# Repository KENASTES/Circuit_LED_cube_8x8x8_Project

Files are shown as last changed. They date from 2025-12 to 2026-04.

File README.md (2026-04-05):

<h1 align="center">Circuit & Electronic 8x8x8 LED Cube Project</h1>

## Overview 
"Repo นี้เป็นโปรเจกวิชา Circuit & Electronic ของผมตอนเรียนอยู่ KMITL โดยโปรเจคนี้เป็นหัวข้อที่ Assign มาจากอาจารย์อีกที โจทย์คือทำ Led Cube ขนาดใดก็ได้โดยจะนำโปรเจคนี้ไปให้เด็กพิการได้ใช้เป็นสื่อในการเรียนรู้ ตัวของโปรเจคเริ่มจากการเลือกใช้ โปรแกรมออกแบบและตัวหน้าที่ต่างๆ เราจะออกแบบ Model ของกล่องที่ใช้เป็นฐานเก็บวงจรและเป็น Base ให้กับตัว Led Cube ด้วย Solid Work 2023 แล้วนำตัวโมเดล Cad ไปปริ้นด้วย 3D Printer อีกที ตัววงจรจะออกแบบด้วย EasyEDA โดยใช้บอร์ด Control เป็น Arduino UNO R4 WIFI แล้วสื่อสารกับตัว Shift Register แบบ Serial in Parallel Out (SIPO) ด้วย Protocol SPI แล้วใช้ Transistor BD241C เป็น Low Side Switch ในการเปิดปิดและรับโหลดของหลอดไฟทั้ง Layer เนื่องจากกระแสในวงจรนั้นสูงมาก จากหลอดไฟ 20mA ทั้งเลเยอร์หรือก็คือ 64 หลอด 64 X 0.02 mA = 1.28A ซึ้งเสเปกโดยทั้วไปอาจจะใช้ขับหลอดไฟภายในเลเยอร์ไม่ได้ในส่วนของโปรแกรมจะสั่ง Input จาก 4X4 KeyPad แล้วใช้เป็น Logic Decision ในการเล่น Animation โดยตัวโค้ดในการออกแบบ Animation จะใช้จินตนาการว่า Led Cube คือการ Integrate พื้นที่ในแคลคูลัสแบบ Discrete 8X8X8 หรือแยก Position เป็น จุดออกมาจากการอินทีเกรตแล้วเขียนกราฟที่มี Animation ลงไปในสมการให้ตัว โหนดแต่ละโหนดเล่นตามสมการจึงเป็นสาเหตุว่าใน Code เป็นสมการแทบจะทั้งหมด"

---

LED Cube Animation

## Tech Stack 
- $\color{cyan}{\textbf{Hardware :}}$ Arduino UNO R4 WIFI, 74HC595
- $\color{orange}{\textbf{Firmware :}}$ C++ (Arduino Framework)
- $\color{purple}{\textbf{Design :}}$ Solid Work 2023, EasyEDA

## Concept 
เราใช้การควบคุมแบบ $8 \times 8 \times 8$ โดยแบ่งเป็น:
- $\color{green}{\textbf{Columns : }}$ 64 จุด ควบคุมผ่าน 8x Shift Registers
- $\color{green}{\textbf{Layers : }}$ 8 ชั้น ควบคุมผ่าน Transistor Darlington Array

## Build Process 
| Building the Jig | Soldering Layers | Final Assembly |
| :---: | :---: | :---: |
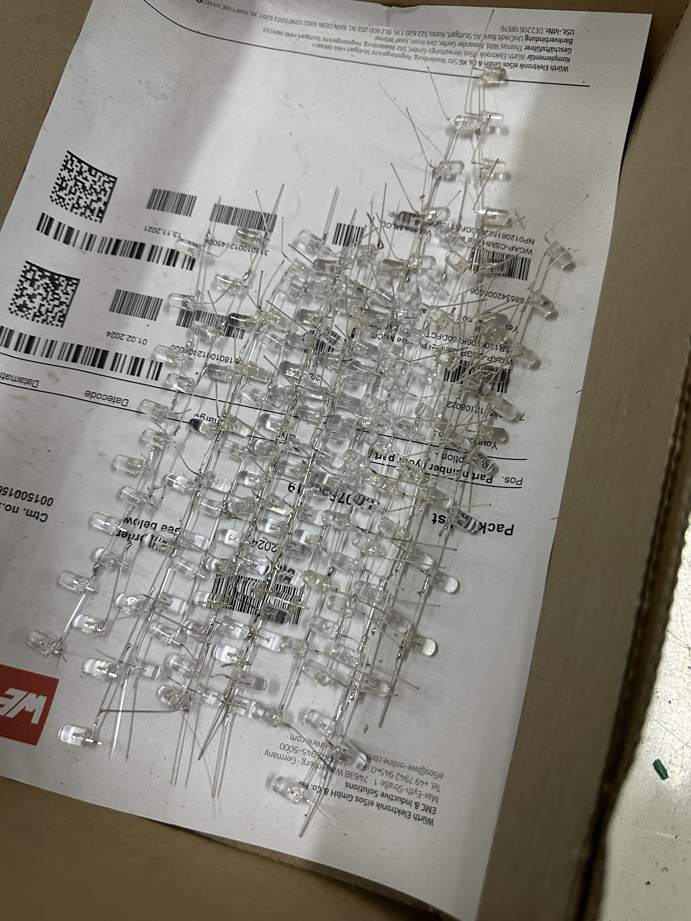
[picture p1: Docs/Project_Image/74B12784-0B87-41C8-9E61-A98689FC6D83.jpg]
Building the Jig
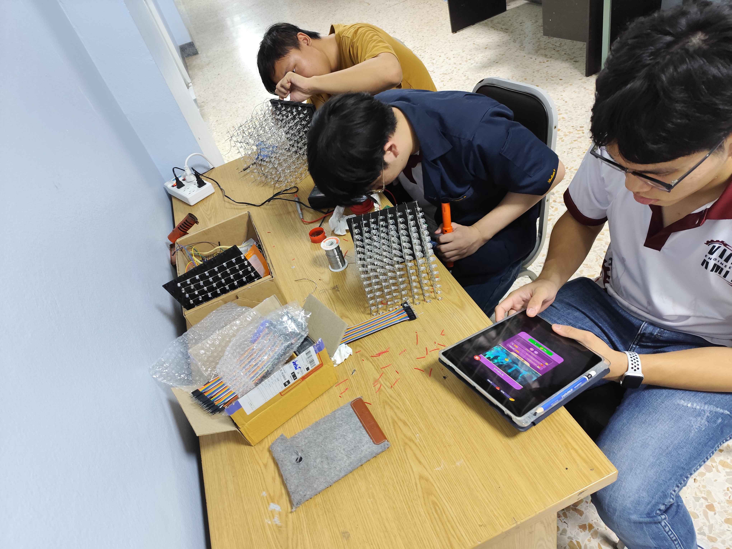
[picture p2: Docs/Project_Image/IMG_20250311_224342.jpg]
Soldering Layers
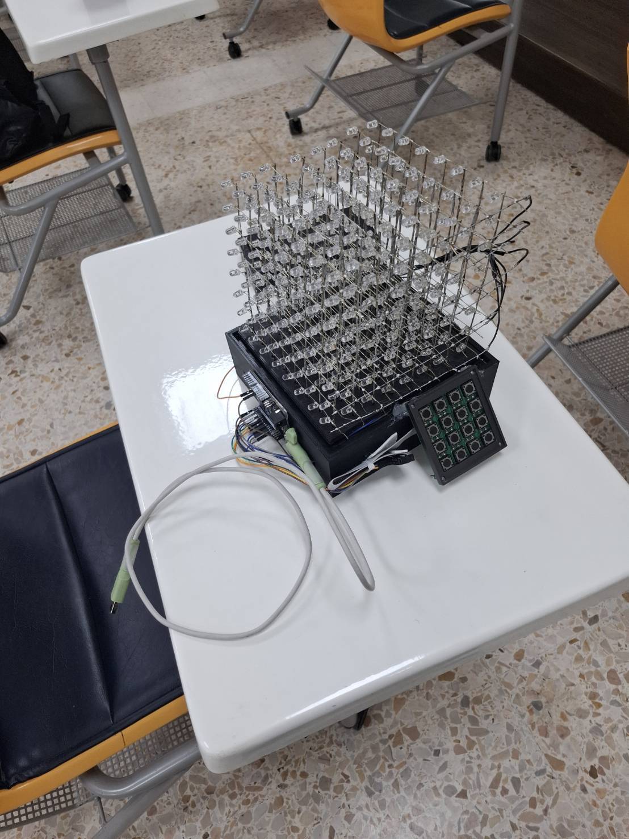
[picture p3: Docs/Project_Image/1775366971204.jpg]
Final Assembly
|  |  |  |

## Contributors 
- $\color{red}{\textbf{Panya Triprom}}$ ([@KENASTES](https://github.com/KENASTES))
- $\color{red}{\textbf{Rathiphat Buakaew}}$ ([@ratiphat2548](https://github.com/ratiphat2548))
- $\color{red}{\textbf{Ploynumthong Chaiyotha}}$ ([@Ploynumthong](https://github.com/Ploynumthong))

---
*Created for Educational Purpose @KMITL*

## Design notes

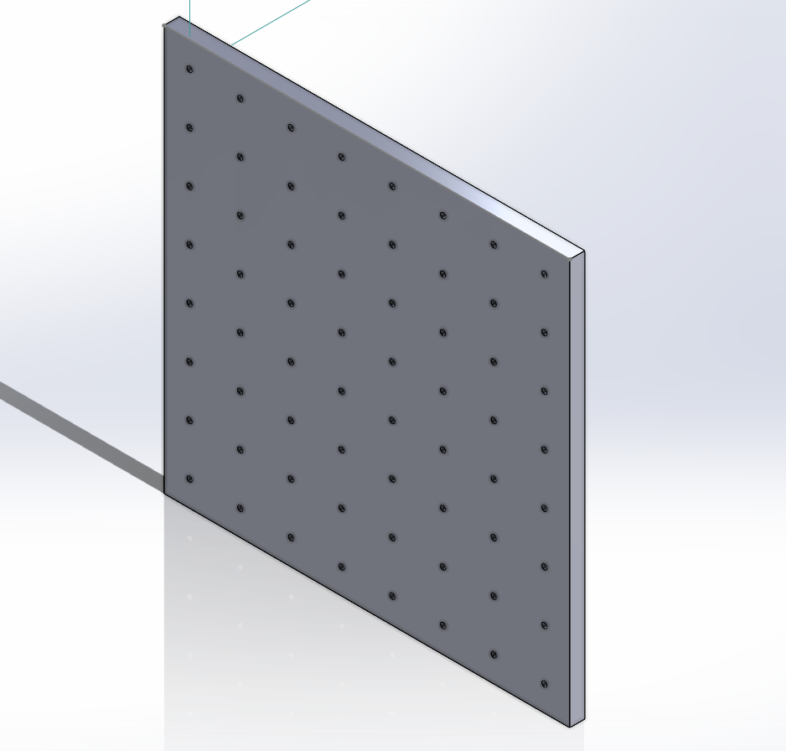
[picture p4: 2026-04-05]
Hardware/Led_Cube_Box_Model/Led Metrix Stand Model View.png

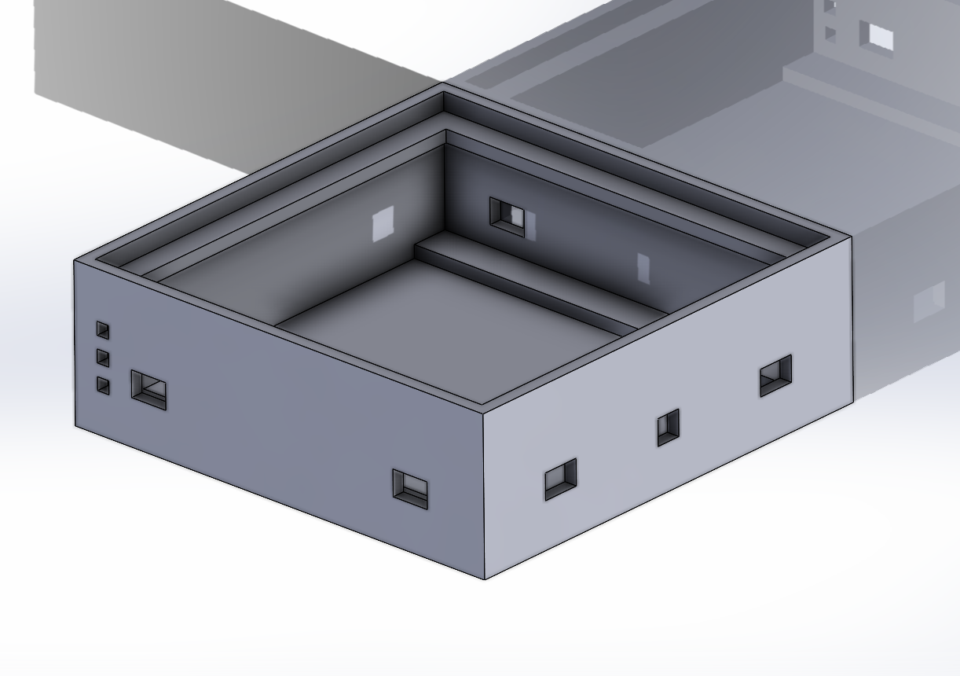
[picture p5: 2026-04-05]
Hardware/Led_Cube_Box_Model/Led Metrix Box Model View.png

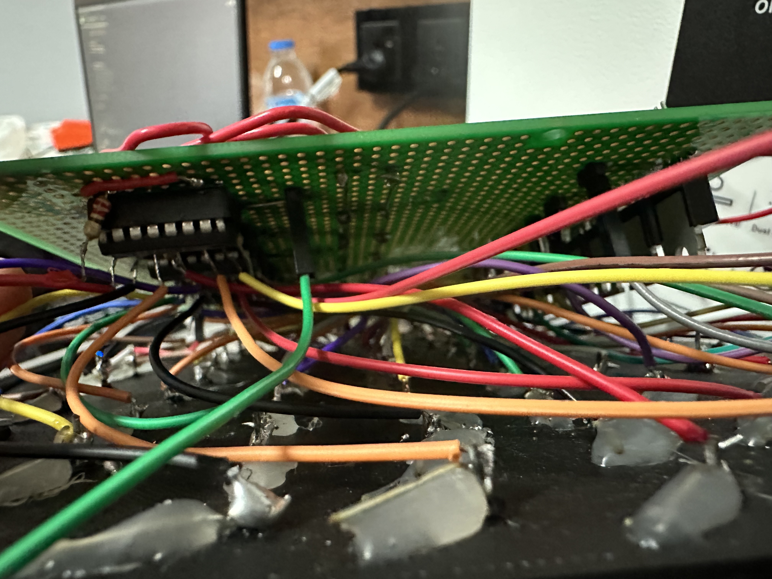
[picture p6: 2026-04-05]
Docs/Project_Image/1E931A35-8066-46A1-B0CE-C7A873FAEA09.jpg

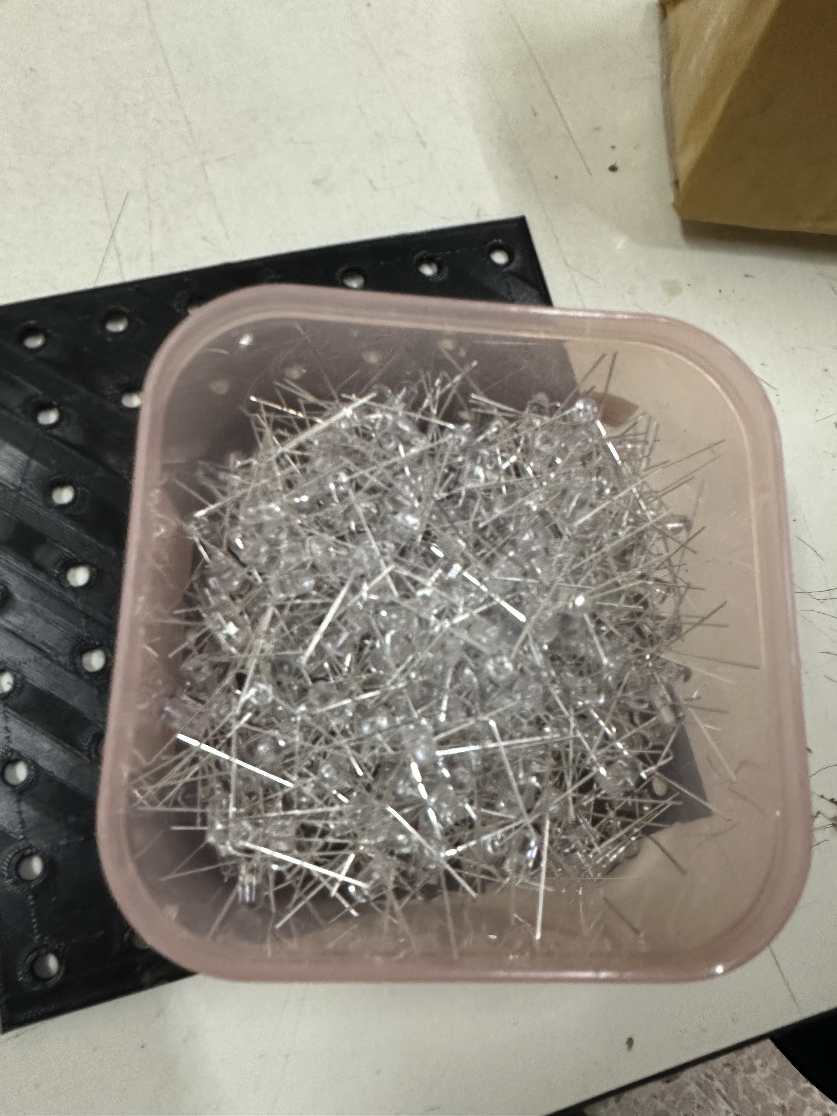
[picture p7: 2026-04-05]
Docs/Project_Image/3936F361-CBBE-4CDA-9E73-F291DBA51588.jpg

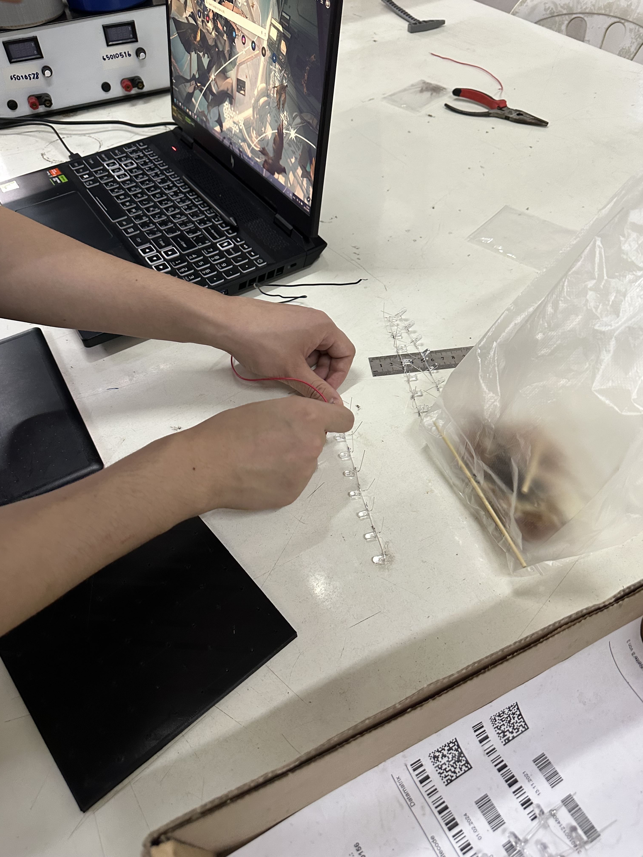
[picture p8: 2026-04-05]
Docs/Project_Image/1FDDD93E-9B1B-4134-BFB7-CA9C1CF94233.jpg

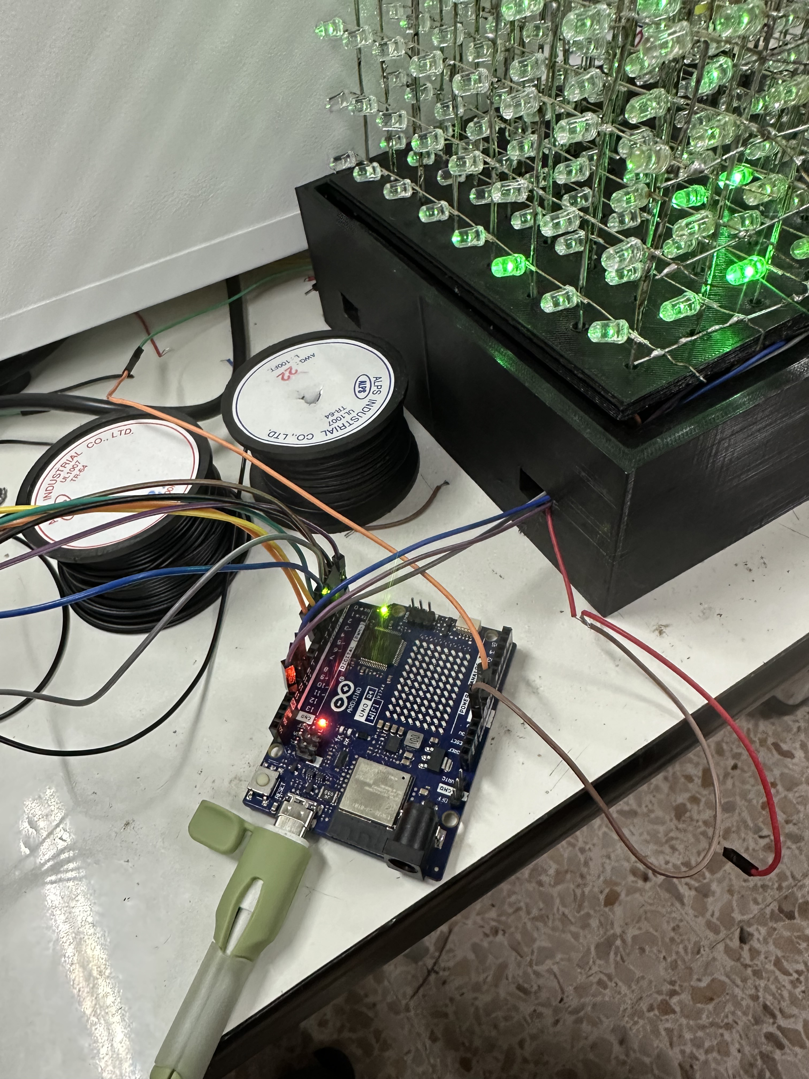
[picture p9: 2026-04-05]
Docs/Project_Image/C7669076-68B3-4732-9814-D13175ADB30F.jpg

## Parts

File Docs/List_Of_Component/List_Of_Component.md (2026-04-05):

# Bill of Materials: 8x8x8 LED Cube Project

โปรเจกต์นี้ใช้การขับ LED แบบ Multiplexing ขนาด 8X8X8 รวม 512 ดวง
ควบคุมด้วย Arduino UNO R4 Wifi และ Shift Registers 74HC595

List                     

Green Light LED 5mm
≈512 pc

74HC595 Shift Registor
8 pc

BD241C Transistor
8 pc

Resistor 220 Ohm 1/4W
≈64 pc

Arduino UNO R4 Wifi
1 Board

4X4 Keypad
1 Panel

Perfboard
1 Panel

Female Pin Header
≈100 pc

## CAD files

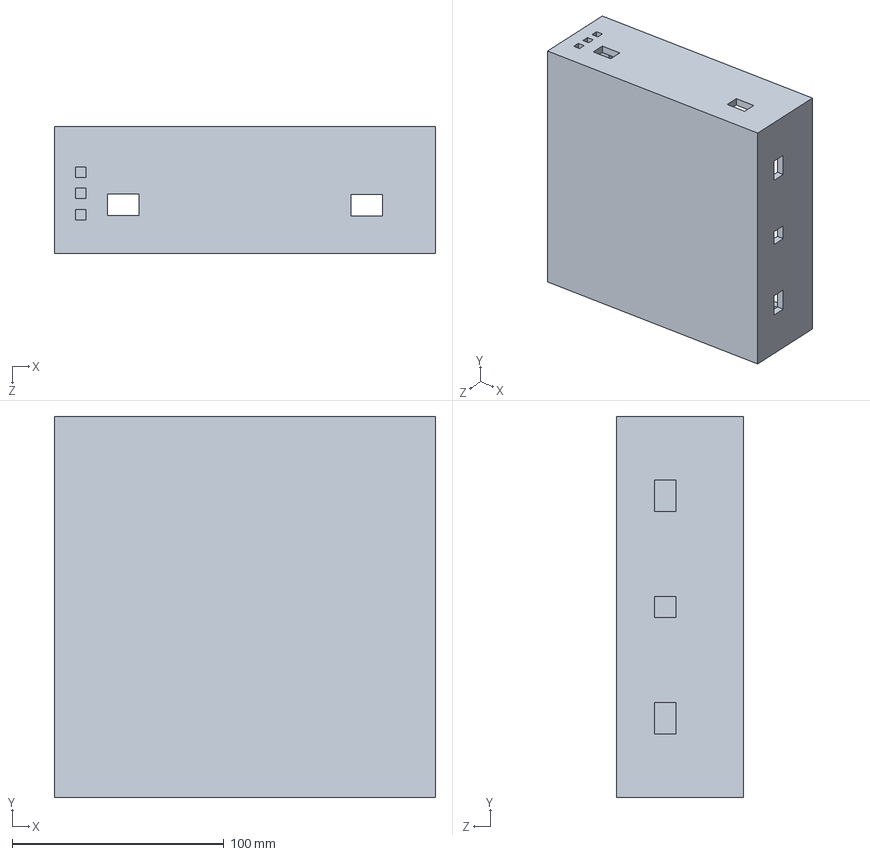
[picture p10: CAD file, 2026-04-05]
Hardware/Led_Cube_Box_Model/Led Metrix Box.SLDPRT
180.0 x 180.0 x 60.0 mm

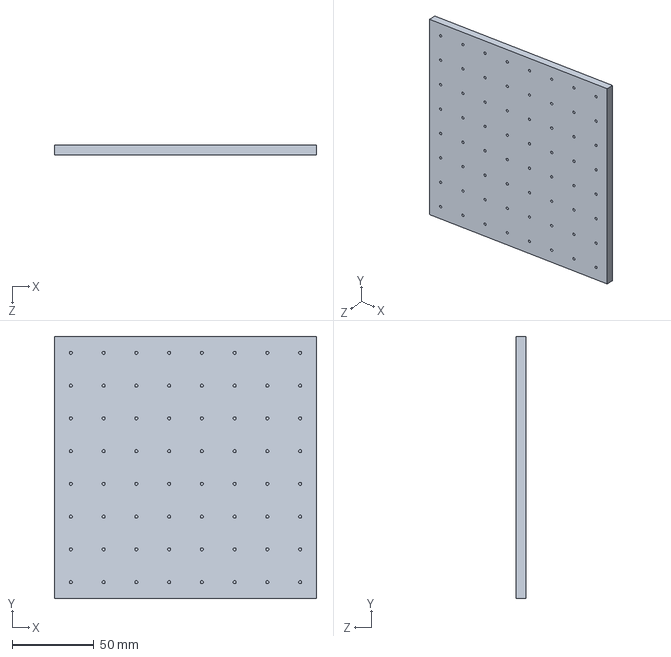
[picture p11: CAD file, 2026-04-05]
Hardware/Led_Cube_Box_Model/Led Metrix Stand.SLDPRT
160.0 x 160.0 x 6.00 mm

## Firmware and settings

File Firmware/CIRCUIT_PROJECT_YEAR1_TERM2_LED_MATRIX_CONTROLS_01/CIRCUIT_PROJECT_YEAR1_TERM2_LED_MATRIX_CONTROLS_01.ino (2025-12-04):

////////// INCLUDE BLOCK //////////
#include <LiquidCrystal_I2C.h>
#include <ArduinoMqttClient.h>
#include <DIYables_Keypad.h>
#include <SPI.h>
/////////////////////////////////////

////////// DEFINE VARIBLE //////////
#define XAXIS 1
#define YAXIS 2
#define ZAXIS 0
#define LAYER_COUNT 8

#define POS_X 0
#define POS_Y 1
#define POS_Z 2
#define NEG_X 3
#define NEG_Y 4
#define NEG_Z 5

#define TOTAL_EFFECTS 12
#define CLEAR 49              //1
#define RAIN 50               //2
#define RANDOMBLINK 51        //3
#define FIREWORK 52        //4
#define WOOP_WOOP 53          //5
#define CUBE_JUMP 54          //6
#define WAVE 55               //7
#define RAINDROP 56           //8
#define LIT 57                //9
#define WTF 65          //10
#define SPARKLE 66            //11
#define CROSSEXPANDEFFECT 67  //12
#define EXP 68              //13
#define PLANE 69              //14
#define PULSE 70               //15
#define GROWTH 71                //16

#define RAIN_TIME 260
#define PLANE_BOING_TIME 180
#define SINE_WAVE_TIME 69
#define WOOP_WOOP_TIME 350
#define CUBE_JUMP_TIME 200
#define GLOW_TIME 8
#define BOUNCE_TIME 500
#define ROTATE_TIME 500
#define FIREWORK_TIME 32
#define WAVE_SLIDE_TIME 250
#define EXPLOSION_TIME 600
#define WAVEY_TIME 250
#define PULSE_TIME 1000
#define HEARTBEAT_TIME 690
/////////////////////////////////////

////////// SETTING VARIBLE //////////
// MATRIX FRAME ของ CUBE
const uint8_t numbers[10][8] = {
  {0x3E, 0x51, 0x49, 0x45, 0x3E, 0x00, 0x00, 0x00}, // 0
  {0x00, 0x42, 0x7F, 0x40, 0x00, 0x00, 0x00, 0x00}, // 1
  {0x72, 0x49, 0x49, 0x49, 0x46, 0x00, 0x00, 0x00}, // 2
  {0x22, 0x41, 0x49, 0x49, 0x36, 0x00, 0x00, 0x00}, // 3
  {0x18, 0x14, 0x12, 0x7F, 0x10, 0x00, 0x00, 0x00}, // 4
  {0x27, 0x45, 0x45, 0x45, 0x39, 0x00, 0x00, 0x00}, // 5
  {0x3E, 0x49, 0x49, 0x49, 0x30, 0x00, 0x00, 0x00}, // 6
  {0x03, 0x01, 0x71, 0x09, 0x07, 0x00, 0x00, 0x00}, // 7
  {0x36, 0x49, 0x49, 0x49, 0x36, 0x00, 0x00, 0x00}, // 8
  {0x06, 0x49, 0x49, 0x49, 0x3E, 0x00, 0x00, 0x00}  // 9
};

uint8_t TEST[1][8] = {
  { 0x24, 0x7e, 0xff, 0x7e, 0x3c, 0x18, 0x0, 0 }
};

// กำหนดสถาณะการเล่นปัจจุบัน
uint8_t cube[8][8];
uint8_t Current_State;

// กำหนดจำนวนแถวใน LCD
const int lcdAddress = 0x27;
const int lcdColumns = 16;
const int lcdRows = 2;

// กำหนดแถวที่จะใช้ใน Keypad
const int ROWS_NUM = 4;
const int COLS_NUM = 4;

// กำหนด ปุ่มใน Matrix Keypad
char keys[ROWS_NUM][COLS_NUM] = {
  { '1', '2', '3', '4' },
  { '5', '6', '7', '8' },
  { '9', 'A', 'B', 'C' },
  { 'D', 'E', 'F', 'G' }
};

// ตั้งตัวแปรค่าเวลา
uint16_t timer;
uint64_t randomTimer;
bool loading;

// กำหนด Pin เข้าของแ่ละแถว
byte pin_cols[COLS_NUM] = { 3, 2, 1, 0 };
byte pin_rows[ROWS_NUM] = { 4, 5, 6, 7 };

// ส่ง parameter ไปให้ฟังชั่นใน Library
DIYables_Keypad keypad = DIYables_Keypad(makeKeymap(keys), pin_rows, pin_cols, ROWS_NUM, COLS_NUM);
LiquidCrystal_I2C lcd(lcdAddress, lcdColumns, lcdRows);
/////////////////////////////////////

////////// SETUP FUNCTION //////////
void setup() {
  // ตั้งย่าน Band สั่ญญาณที่จะอ่าน
  Serial.begin(115200);
  // Setting LED CUBE
  loading = true;
  randomTimer = 0;
  Current_State = 0;
  SPI.begin();
  SPI.beginTransaction(SPISettings(8000000, MSBFIRST, SPI_MODE0));
  randomSeed(analogRead(0));

  // Setup จอ LCD
  lcd.begin();
  lcd.backlight();
  lcd.setCursor(0, 0);
}

////////// LOOP FUNCTION //////////
void loop() {
  unsigned long currentMillis = millis();
  // ให้ตัว Timer นับไปเรื่อยๆ
  randomTimer++;
  char Input_Key = keypad.getKey();
  // จับค่าปุ่มกดที่กดเข้ามา
  if (Input_Key) {
    Serial.println(Input_Key);
    Current_State = Input_Key;
  }

  if (Current_State == 49) {
    clearCube();
  }

  switch (Current_State) {
    case CLEAR: clearALL(); break;
    case RAIN: rain(); break;                            //2
    case RANDOMBLINK: randomBlink(); break;              //3
    case FIREWORK: fireworkEffect(); break;               //4
    case WOOP_WOOP: woopWoop(); break;                   //5
    case CUBE_JUMP: cubeJump(); break;                   //6
    case WAVE: waveyUpDownEffect(); break;                      //7
    case RAINDROP: RainDrop(); break;                    //8
    case LIT: lit(); break;                              //9
    case WTF: heartbeatEffect(); break;              //10
    case SPARKLE: sparkle(); break;                      //11
    case CROSSEXPANDEFFECT: crossExpandEffect(); break;  //12
    case EXP: explosionEffect(); break;                    //13
    case PLANE: planeBoing(); break;                     //14
    case PULSE: pulseEffect(); break;                //15
    case GROWTH: bouncingBallEffect(); break;                    //16
    default: clearCube();
  }
  renderCube();
}

/////////////////////////////////////

////////// CUBE FUNCTION //////////
// Set Array 3 มิติ
void setVoxel(uint8_t x, uint8_t y, uint8_t z) {
  cube[7 - y][7 - z] |= (0x01 << x);
}

// Set Array 3 มิติ
void clearVoxel(uint8_t x, uint8_t y, uint8_t z) {
  cube[7 - y][7 - z] ^= (0x01 << x);
}

// Set Array 3 มิติ
bool getVoxel(uint8_t x, uint8_t y, uint8_t z) {
  return (cube[7 - y][7 - z] & (0x00 << x)) == (0x00 << x);
}

void updateCube() {
  for (int layer = 0; layer < LAYER_COUNT; layer++) {
    SPI.transfer(0x01 << layer);
    for (int row = 0; row < 8; row++) {
      SPI.transfer(cube[layer][row]);
    }
    digitalWrite(10, HIGH);
    delay(10);
  }
}

void waveyUpDownEffect() {
  static uint8_t phase = 0;

  if (loading) {
    clearCube();
    phase = 0;
    loading = false;
  }

  timer++;
  if (timer > WAVEY_TIME) {
    timer = 0;
    clearCube();
    for (uint8_t x = 0; x < 8; x++) {
      for (uint8_t y = 0; y < 8; y++) {
        uint8_t z = 4 + 3 * sin((x + y + phase) * PI / 8);
        setVoxel(x, y, z);
      }
    }

    phase++;
    if (phase >= 16) phase = 0;
  }
}

void randomBlink() {
  for (int i = 0; i < 1; i++) {
    clearCube();
    for (int j = 0; j < 25; j++) {
      int x = random(0, 8);
      int y = random(0, 8);
      int z = random(0, 8);
      cube[z][y] |= (1 << x);
    }
    updateCube();
    delay(10);
  }
}

void sparkle() {
  for (int i = 0; i < 1; i++) {
    clearCube();
    for (int j = 0; j < 3; j++) {
      int x = random(0, 8);
      int y = random(0, 8);
      int z = random(0, 8);
      cube[z][y] |= (1 << x);
    }
    updateCube();
    delay(100);
  }
}

// ขยับ Bit ของ Array 3 มิติ
void shift(uint8_t dir) {

  if (dir == POS_X) {
    for (uint8_t y = 0; y < 8; y++) {
      for (uint8_t z = 0; z < 8; z++) {
        cube[y][z] = cube[y][z] << 1;
      }
    }
  } else if (dir == NEG_X) {
    for (uint8_t y = 0; y < 8; y++) {
      for (uint8_t z = 0; z < 8; z++) {
        cube[y][z] = cube[y][z] >> 1;
      }
    }
  } else if (dir == POS_Y) {
    for (uint8_t y = 1; y < 8; y++) {
      for (uint8_t z = 0; z < 8; z++) {
        cube[y - 1][z] = cube[y][z];
      }
    }
    for (uint8_t i = 0; i < 8; i++) {
      cube[7][i] = 0;
    }
  } else if (dir == NEG_Y) {
    for (uint8_t y = 7; y > 0; y--) {
      for (uint8_t z = 0; z < 8; z++) {
        cube[y][z] = cube[y - 1][z];
      }
    }
    for (uint8_t i = 0; i < 8; i++) {
      cube[0][i] = 0;
    }
  } else if (dir == POS_Z) {
    for (uint8_t y = 0; y < 8; y++) {
      for (uint8_t z = 1; z < 8; z++) {
        cube[y][z - 1] = cube[y][z];
      }
    }
    for (uint8_t i = 0; i < 8; i++) {
      cube[i][7] = 0;
    }
  } else if (dir == NEG_Z) {
    for (uint8_t y = 0; y < 8; y++) {
      for (uint8_t z = 7; z > 0; z--) {
        cube[y][z] = cube[y][z - 1];
      }
    }
    for (uint8_t i = 0; i < 8; i++) {
      cube[i][0] = 0;
    }
  }
}

// Bit สั่งไฟ ON
void lightCube() {
  for (uint8_t i = 0; i < 8; i++) {
    for (uint8_t j = 0; j < 8; j++) {
      cube[i][j] = 0xFF;
    }
  }
}

// Bit สั่งไฟ OFF
void clearCube() {
  for (uint8_t i = 0; i < 8; i++) {
    for (uint8_t j = 0; j < 8; j++) {
      cube[i][j] = 0;
    }
  }
}

// Bit สั่ง 3 มิติ
void drawCube(uint8_t x, uint8_t y, uint8_t z, uint8_t s) {
  for (uint8_t i = 0; i < s; i++) {
    setVoxel(x, y + i, z);
    setVoxel(x + i, y, z);
    setVoxel(x, y, z + i);
    setVoxel(x + s - 1, y + i, z + s - 1);
    setVoxel(x + i, y + s - 1, z + s - 1);
    setVoxel(x + s - 1, y + s - 1, z + i);
    setVoxel(x + s - 1, y + i, z);
    setVoxel(x, y + i, z + s - 1);
    setVoxel(x + i, y + s - 1, z);
    setVoxel(x + i, y, z + s - 1);
    setVoxel(x + s - 1, y, z + i);
    setVoxel(x, y + s - 1, z + i);
  }
}

// Setting แต่ละ Layer
void setPlane(uint8_t axis, uint8_t i) {
  for (uint8_t j = 0; j < 8; j++) {
    for (uint8_t k = 0; k < 8; k++) {
      if (axis == XAXIS) {
        setVoxel(i, j, k);
      } else if (axis == YAXIS) {
        setVoxel(j, i, k);
      } else if (axis == ZAXIS) {
        setVoxel(j, k, i);
      }
    }
  }
}

// รีเซ็ต CUBE ทุกๆ Loop
void renderCube() {
  for (uint8_t i = 0; i < 8; i++) {
    digitalWrite(SS, LOW);
    SPI.transfer(0x01 << i);
    for (uint8_t j = 0; j < 8; j++) {
      SPI.transfer(cube[i][j]);
    }
    digitalWrite(SS, HIGH);
  }
}

// RAIN ANIMATION
void rain() {
  if (loading) {
    clearCube();
    loading = false;
  }
  timer++;
  if (timer > RAIN_TIME) {
    timer = 0;
    shift(NEG_Y);
    uint8_t numDrops = random(0, 5);
    for (uint8_t i = 0; i < numDrops; i++) {
      setVoxel(random(0, 8), 7, random(0, 8));
    }
  }
}

void RainDrop() {
  for (int i = 0; i < 1; i++) {
    clearCube();
    for (int j = 0; j < 1; j++) {
      int x = random(0, 8);
      int y = random(0, 8);
      for (int z = 7; z >= 0; z--) {
        cube[7 - z][y] |= (1 << x);
        updateCube();
        delay(2);
        cube[7 - z][y] &= ~(1 << x);
      }
    }
  }
}

// SENDVOXELS VARIBLES
uint8_t selX = 0;
uint8_t selY = 0;
uint8_t selZ = 0;
uint8_t sendDirection = 0;
bool sending = false;

void fireworkEffect() {
  if (loading) {
    clearCube();
    loading = false;
  }

  timer++;
  if (timer > FIREWORK_TIME) {
    timer = 0;
    clearCube();

    uint8_t cx = 4, cy = 4, cz = 4;
    for (uint8_t i = 0; i < 8; i++) {
      int dx = random(-3, 4);
      int dy = random(-3, 4);
      int dz = random(-3, 4);
      if (cx + dx < 8 && cy + dy < 8 && cz + dz < 8) {
        setVoxel(cx + dx, cy + dy, cz + dz);
      }
    }

    // เพิ่มการกระจายเหมือนระเบิดดอกไม้ไฟ
    for (uint8_t i = 0; i < 10; i++) {
      int dx = random(-3, 4);
      int dy = random(-3, 4);
      int dz = random(-3, 4);
      setVoxel(cx + dx, cy + dy, cz + dz);
    }
  }
}

// WOOPWOOP VARIBLE
uint8_t cubeSize = 0;
bool cubeExpanding = true;

// WOOPWOOP ANIMATION
void woopWoop() {
  if (loading) {
    clearCube();
    cubeSize = 2;
    cubeExpanding = true;
    loading = false;
  }

  timer++;
  if (timer > WOOP_WOOP_TIME) {
    timer = 0;
    if (cubeExpanding) {
      cubeSize += 2;
      if (cubeSize == 8) {
        cubeExpanding = false;
      }
    } else {
      cubeSize -= 2;
      if (cubeSize == 2) {
        cubeExpanding = true;
      }
    }
    clearCube();
    drawCube(4 - cubeSize / 2, 4 - cubeSize / 2, 4 - cubeSize / 2, cubeSize);
  }
}

// CUBEJUMP VARIBLE
uint8_t xPos;
uint8_t yPos;
uint8_t zPos;

// CUBEJUMP ANIMATION
void cubeJump() {
  if (loading) {
    clearCube();
    xPos = random(0, 2) * 7;
    yPos = random(0, 2) * 7;
    zPos = random(0, 2) * 7;
    cubeSize = 8;
    cubeExpanding = false;
    loading = false;
  }

  timer++;
  if (timer > CUBE_JUMP_TIME) {
    timer = 0;
    clearCube();
    if (xPos == 0 && yPos == 0 && zPos == 0) {
      drawCube(xPos, yPos, zPos, cubeSize);
    } else if (xPos == 7 && yPos == 7 && zPos == 7) {
      drawCube(xPos + 1 - cubeSize, yPos + 1 - cubeSize, zPos + 1 - cubeSize, cubeSize);
    } else if (xPos == 7 && yPos == 0 && zPos == 0) {
      drawCube(xPos + 1 - cubeSize, yPos, zPos, cubeSize);
    } else if (xPos == 0 && yPos == 7 && zPos == 0) {
      drawCube(xPos, yPos + 1 - cubeSize, zPos, cubeSize);
    } else if (xPos == 0 && yPos == 0 && zPos == 7) {
      drawCube(xPos, yPos, zPos + 1 - cubeSize, cubeSize);
    } else if (xPos == 7 && yPos == 7 && zPos == 0) {
      drawCube(xPos + 1 - cubeSize, yPos + 1 - cubeSize, zPos, cubeSize);
    } else if (xPos == 0 && yPos == 7 && zPos == 7) {
      drawCube(xPos, yPos + 1 - cubeSize, zPos + 1 - cubeSize, cubeSize);
    } else if (xPos == 7 && yPos == 0 && zPos == 7) {
      drawCube(xPos + 1 - cubeSize, yPos, zPos + 1 - cubeSize, cubeSize);
    }
    if (cubeExpanding) {
      cubeSize++;
      if (cubeSize == 8) {
        cubeExpanding = false;
        xPos = random(0, 2) * 7;
        yPos = random(0, 2) * 7;
        zPos = random(0, 2) * 7;
      }
    } else {
      cubeSize--;
      if (cubeSize == 1) {
        cubeExpanding = true;
      }
    }
  }
}

// LIT ANIMATION
void lit() {
  clearCube();
  for (uint8_t i = 0; i < 8; i++) {
    for (uint8_t j = 0; j < 8; j++) {
      cube[i][j] = 0xFF;
    }
  }
}

void crossExpandEffect() {
  for (int size = 0; size < 4; size++) {
    clearCube();
    for (int layer = 0; layer < 8; layer++) {
      for (int row = 0; row < 8; row++) {
        if (row == 4 - size || row == 4 + size) cube[layer][row] = 0b11111111;
      }
    }
    updateCube();
    delay(150);
  }
}

uint8_t planePosition = 0;
uint8_t planeDirection = 0;
bool looped = false;

void planeBoing() {
  if (loading) {
    clearCube();
    uint8_t axis = random(0, 2);
    planePosition = random(0, 2) * 7;
    setPlane(axis, planePosition);
    if (axis == XAXIS) {
      if (planePosition == 0) {
        planeDirection = POS_X;
      } else {
        planeDirection = NEG_X;
      }
    } else if (axis == YAXIS) {
      if (planePosition == 0) {
        planeDirection = POS_Y;
      } else {
        planeDirection = NEG_Y;
      }
    } else if (axis == ZAXIS) {
      if (planePosition == 0) {
        planeDirection = POS_Z;
      } else {
        planeDirection = NEG_Z;
      }
    }
    timer = 0;
    looped = false;
    loading = false;
  }

  timer++;
  if (timer > PLANE_BOING_TIME) {
    timer = 0;
    shift(planeDirection);
    if (planeDirection % 2 == 0) {
      planePosition++;
      if (planePosition == 7) {
        if (looped) {
          loading = true;
        } else {
          planeDirection++;
          looped = true;
        }
      }
    } else {
      planePosition--;
      if (planePosition == 0) {
        if (looped) {
          loading = true;
        } else {
          planeDirection--;
          looped = true;
        }
      }
    }
  }
}

void pulseEffect() {
  static uint8_t pulseSize = 0;
  static bool expanding = true;

  if (loading) {
    clearCube();
    pulseSize = 1;
    expanding = true;
    loading = false;
  }

  timer++;
  if (timer > PULSE_TIME) {
    timer = 0;
    clearCube();
    
    if (expanding) {
      pulseSize++;
      if (pulseSize == 8) expanding = false;
    } else {
      pulseSize--;
      if (pulseSize == 1) expanding = true;
    }
    
    drawCube(4 - pulseSize / 2, 4 - pulseSize / 2, 4 - pulseSize / 2, pulseSize);
  }
}

void explosionEffect() {
  if (loading) {
    clearCube();
    loading = false;
  }

  timer++;
  if (timer > EXPLOSION_TIME) {
    timer = 0;
    clearCube();

    uint8_t cx = 4, cy = 4, cz = 4;
    for (uint8_t i = 0; i < 10; i++) {
      int dx = random(-3, 4);
      int dy = random(-3, 4);
      int dz = random(-3, 4);
      if (cx + dx < 8 && cy + dy < 8 && cz + dz < 8) {
        setVoxel(cx + dx, cy + dy, cz + dz);
      }
    }
  }
}

void bouncingBallEffect() {
  static uint8_t ballPosX = 0;
  static uint8_t ballPosY = 0;
  static uint8_t ballPosZ = 0;
  static int8_t xSpeed = 1;
  static int8_t ySpeed = 1;
  static int8_t zSpeed = 1;

  if (loading) {
    clearCube();
    ballPosX = random(0, 8);
    ballPosY = random(0, 8);
    ballPosZ = random(0, 8);
    xSpeed = random(1, 2);
    ySpeed = random(1, 2);
    zSpeed = random(1, 2);
    loading = false;
  }

  timer++;
  if (timer > BOUNCE_TIME) {
    timer = 0;
    clearCube();

    // วาดลูกบอล
    setVoxel(ballPosX, ballPosY, ballPosZ);

    // อัพเดทตำแหน่งลูกบอล
    ballPosX += xSpeed;
    ballPosY += ySpeed;
    ballPosZ += zSpeed;

    // เช็คการชนขอบ
    if (ballPosX == 0 || ballPosX == 7) xSpeed = -xSpeed;
    if (ballPosY == 0 || ballPosY == 7) ySpeed = -ySpeed;
    if (ballPosZ == 0 || ballPosZ == 7) zSpeed = -zSpeed;
  }
}

void heartbeatEffect() {
  static uint8_t heartbeatState = 0;

  if (loading) {
    clearCube();
    heartbeatState = 0;
    loading = false;
  }

  timer++;
  if (timer > HEARTBEAT_TIME) {
    timer = 0;

    if (heartbeatState == 0) {
      // ทำให้ไฟลุกขึ้นเล็กน้อย
      for (uint8_t i = 0; i < 8; i++) {
        for (uint8_t j = 0; j < 8; j++) {
          cube[i][j] = 0xFF;
        }
      }
      heartbeatState = 1;
    } else {
      // ทำให้ไฟหรี่ลง
      clearCube();
      heartbeatState = 0;
    }
    updateCube();
  }
}

void clearALL() {
  for (uint8_t x = 0; x < 8; x++) {
    for (uint8_t y = 0; y < 8; y++) {
      for (uint8_t z = 0; z < 8; z++) {
        setVoxel(x, y, z);  // ปิดไฟที่ (x, y, z)
      }
    }
  }
  updateCube();  // อัพเดตสถานะใหม่ให้ Cube
}

/////////////////////////////////////

////////// MATRIX KEYBOARD FUNCTION //////////

/////////////////////////////////////

////////// LCD DISPLAY FUNCTION //////////
char Setup_massage[20] = "  Setting   up  ";
char Raining_Effect[20] = "    Raining     ";
char Raining_Discription[20] = " Find a shelter ";
/////////////////////////////////////

////////// LCD DISPLAY FUNCTION //////////
void Settingup_Display() {
  lcd.setCursor(0, 0);
  for (int Loop = 0; Loop <= 16; Loop++) {
    lcd.print(Setup_massage[Loop]);
  }
}

void Raining_Status_Display() {
  lcd.setCursor(0, 0);
  for (int Loop = 0; Loop <= 16; Loop++) {
    lcd.print(Raining_Effect[Loop]);
  }
  lcd.setCursor(0, 1);
  for (int Loop = 0; Loop <= 16; Loop++) {
    lcd.print(Raining_Discription[Loop]);
  }
}
/////////////////////////////////////

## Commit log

2025-12-04 Upload Led cube code
2026-04-05 Change the Hardware Path Which Certain a single file via move the schematic outside the folder
2026-04-05 Add Motiple Major File
    [Led Metrix Box.SLDPRT, Led Metrix Stand.SLDPRT]
